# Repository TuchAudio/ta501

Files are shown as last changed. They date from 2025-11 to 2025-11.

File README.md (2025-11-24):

# ta501
Input Selector Board

## Purpose
Basic input board for **[TuchAudio 303](../../../ta303) integrated amplifier**, a.k.a. _The Bedroom Amp_, together with:

- [TuchAudio 103](../../../ta103): Phono pre-amp.
- [TuchAudio 202](../../../ta202): compact power amp.
- A generic **12V/2A power supply**

## Inputs

- **Phono:** 3.6 mV / 110 kohm. (via the [103 pre-amp](../../../ta103), otherwise same as line input)
- **Line:** 180 mV / 900 kohm.
- **Tape Playback:** thru RCA (180 mV/47 k) and DIN (0.48 V/16.5 k) connectors.

## Outputs

- Line out: 180 mV (intended for a suitable poweramp, like [TuchAudio 202](../../../ta202)).
- Tape Rec (RCA): 180 mV
- Tape Rec (DIN): 5.3 mV over 10 kohm

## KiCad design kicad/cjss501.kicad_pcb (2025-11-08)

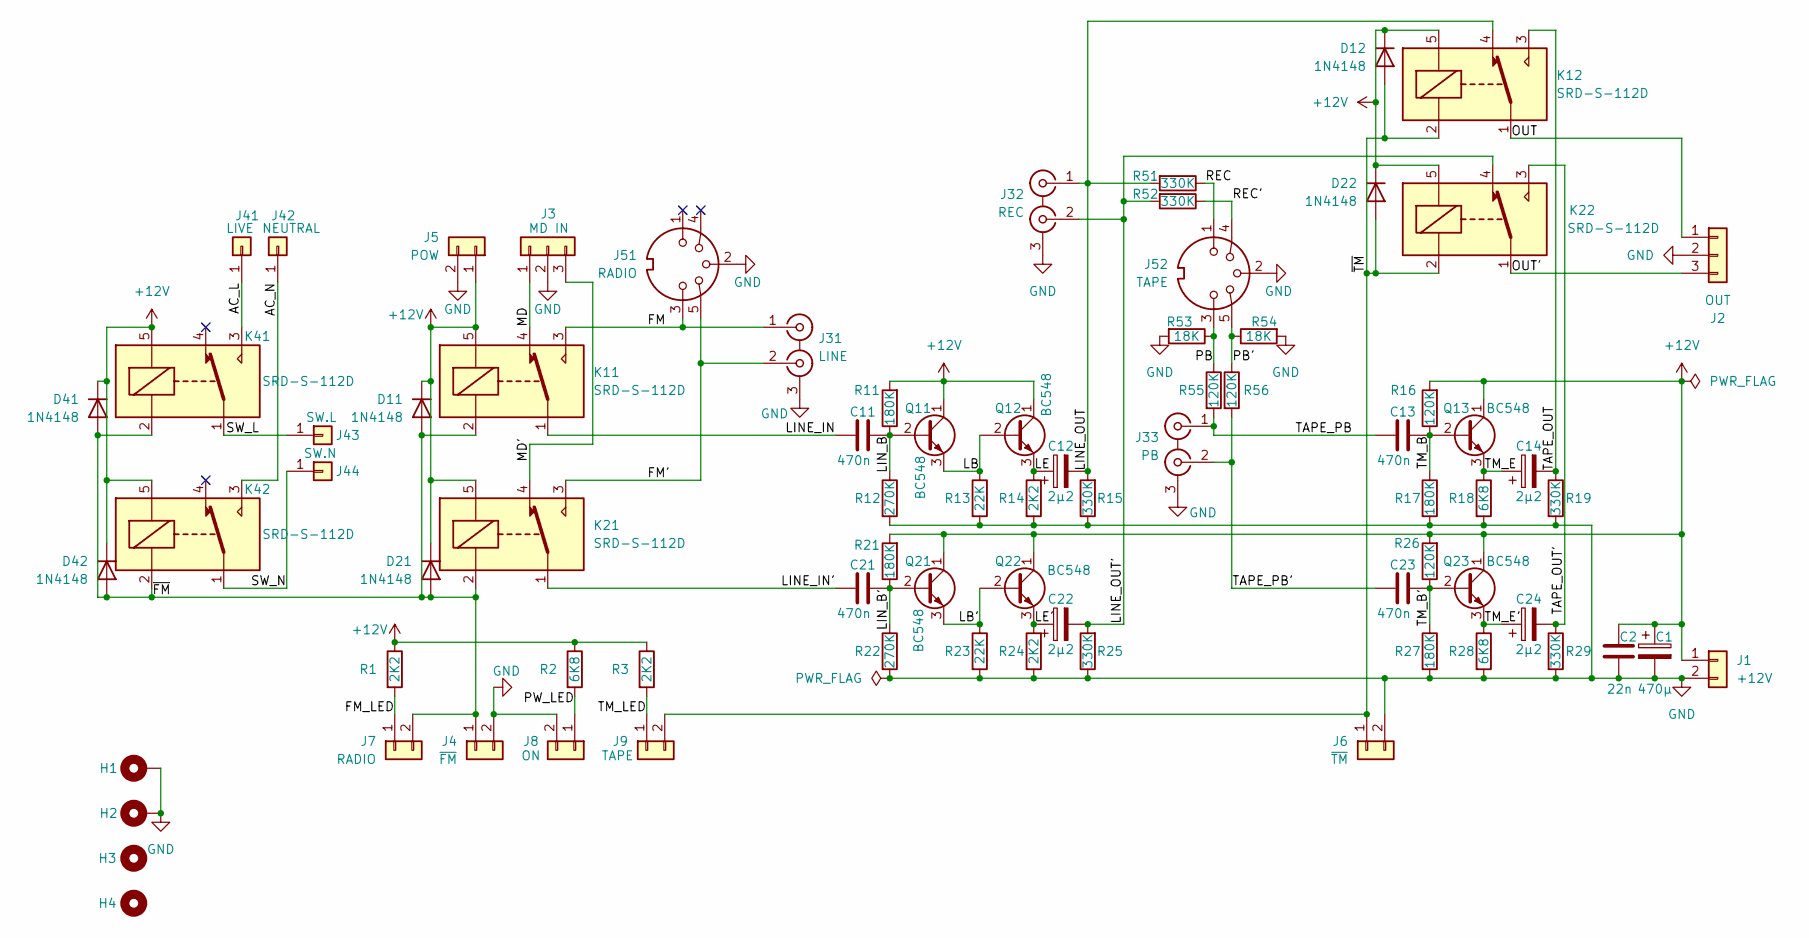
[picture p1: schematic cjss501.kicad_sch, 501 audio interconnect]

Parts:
C1: 470µ; CP_Radial_D6.3mm_P2.50mm
C2: 22n; C_Disc_D6.0mm_W2.5mm_P5.00mm
C11, C13, C21, C23: 470n; C_Rect_L7.2mm_W3.0mm_P5.00mm_FKS2_FKP2_MKS2_MKP2
C12, C14, C22, C24: 2µ2; CP_Radial_D4.0mm_P1.50mm
D11, D12, D21, D22, D41, D42: 1N4148; D_DO-35_SOD27_P7.62mm_Horizontal
H1, H2: MountingHole_Pad; MountingHole_3.2mm_M3_DIN965_Pad
H3, H4: MountingHole; MountingHole_3.2mm_M3
J1: +12V; PinHeader_1x02_P2.54mm_Vertical
J2: OUT; PinHeader_1x03_P2.54mm_Vertical
J3: MD IN; PinHeader_1x03_P2.54mm_Vertical
J4: ~{FM}; PinHeader_1x02_P2.54mm_Vertical
J5: POW; PinHeader_1x02_P2.54mm_Vertical
J6: ~{TM}; PinHeader_1x02_P2.54mm_Vertical
J7: RADIO; PinHeader_1x02_P2.54mm_Vertical
J8: ON; PinHeader_1x02_P2.54mm_Vertical
J9: TAPE; PinHeader_1x02_P2.54mm_Vertical
J31: LINE; 2xRCA_vertical
J32: REC; 2xRCA_vertical
J33: PB; 2xRCA_vertical
J41: LIVE; PinHeader_1x01_P2.54mm_Vertical
J42: NEUTRAL; PinHeader_1x01_P2.54mm_Vertical
J43: SW.L; PinHeader_1x01_P2.54mm_Vertical
J44: SW.N; PinHeader_1x01_P2.54mm_Vertical
J51: RADIO; DIN 5-180deg
J52: TAPE; DIN 5-180deg
K11, K12, K21, K22, K41, K42: SRD-S-112D; Relay_SPDT_SANYOU_SRD_Series_Form_C
Q11, Q12, Q13, Q21, Q22, Q23: BC548; TO-92_Inline
R1, R3, R14, R24: 2K2; R_Axial_DIN0207_L6.3mm_D2.5mm_P2.54mm_Vertical
R2, R18, R28: 6K8; R_Axial_DIN0207_L6.3mm_D2.5mm_P2.54mm_Vertical
R11, R17, R21, R27: 180K; R_Axial_DIN0207_L6.3mm_D2.5mm_P2.54mm_Vertical
R12, R22: 270K; R_Axial_DIN0207_L6.3mm_D2.5mm_P2.54mm_Vertical
R13, R23: 22K; R_Axial_DIN0207_L6.3mm_D2.5mm_P2.54mm_Vertical
R15, R19, R25, R29, R51, R52: 330K; R_Axial_DIN0207_L6.3mm_D2.5mm_P2.54mm_Vertical
R16, R26, R55, R56: 120K; R_Axial_DIN0207_L6.3mm_D2.5mm_P2.54mm_Vertical
R53, R54: 18K; R_Axial_DIN0207_L6.3mm_D2.5mm_P2.54mm_Vertical

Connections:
+12V: C1.1, C2.1, D11.1 (K), D12.1 (K), D21.1 (K), D22.1 (K), D41.1 (K), D42.1 (K), J1.1, J5.1, K11.5, K12.5, K21.5, K22.5, K41.5, K42.5, Q11.1 (C), Q12.1 (C), Q13.1 (C), Q21.1 (C), Q22.1 (C), Q23.1 (C), R1.1, R2.1, R3.1, R11.2, R16.2, R21.2, R26.2
/AC_L: J41.1, K41.3
/AC_N: J42.1, K42.3
/FM: J31.1 (IN1), J51.3, K11.3
/FM': J31.2 (IN2), J51.5, K21.3
/FM_LED: J7.1, R1.2
/LB: Q11.3 (E), Q12.2 (B), R13.1
/LB': Q21.3 (E), Q22.2 (B), R23.1
/LE: C12.1, Q12.3 (E), R14.1
/LE': C22.1, Q22.3 (E), R24.1
/LINE_IN: C11.1, K11.1
/LINE_IN': C21.1, K21.1
/LINE_OUT: C12.2, J32.1 (IN1), K12.4, R15.2, R51.2
/LINE_OUT': C22.2, J32.2 (IN2), K22.4, R25.2, R52.2
/LIN_B: C11.2, Q11.2 (B), R11.1, R12.1
/LIN_B': C21.2, Q21.2 (B), R21.1, R22.1
/MD: J3.1, K11.4
/MD': J3.3, K21.4
/OUT: J2.1, K12.1
/OUT': J2.3, K22.1
/PB: J52.3, R53.1, R55.1
/PB': J52.5, R54.1, R56.1
/PW_LED: J8.1, R2.2
/REC: J52.1, R51.1
/REC': J52.4, R52.1
/SW_L: J43.1, K41.1
/SW_N: J44.1, K42.1
/TAPE_OUT: C14.2, K12.3, R19.1
/TAPE_OUT': C24.2, K22.3, R29.1
/TAPE_PB: C13.1, J33.1 (IN1), R55.2
/TAPE_PB': C23.1, J33.2 (IN2), R56.2
/TM_B: C13.2, Q13.2 (B), R16.1, R17.1
/TM_B': C23.2, Q23.2 (B), R26.1, R27.1
/TM_E: C14.1, Q13.3 (E), R18.1
/TM_E': C24.1, Q23.3 (E), R28.1
/TM_LED: J9.1, R3.2
/~FM: D11.2 (A), D21.2 (A), D41.2 (A), D42.2 (A), J4.1, J7.2, K11.2, K21.2, K41.2, K42.2
/~TM: D12.2 (A), D22.2 (A), J6.1, J9.2, K12.2, K22.2
GND: C1.2, C2.2, H1.1, H2.1, J1.2, J2.2, J3.2, J4.2, J5.2, J6.2, J8.2, J31.3 (EXT), J32.3 (EXT), J33.3 (EXT), J51.2, J52.2, R12.2, R13.2, R14.2, R15.1, R17.2, R18.2, R19.2, R22.2, R23.2, R24.2, R25.1, R27.2, R28.2, R29.2, R53.2, R54.2

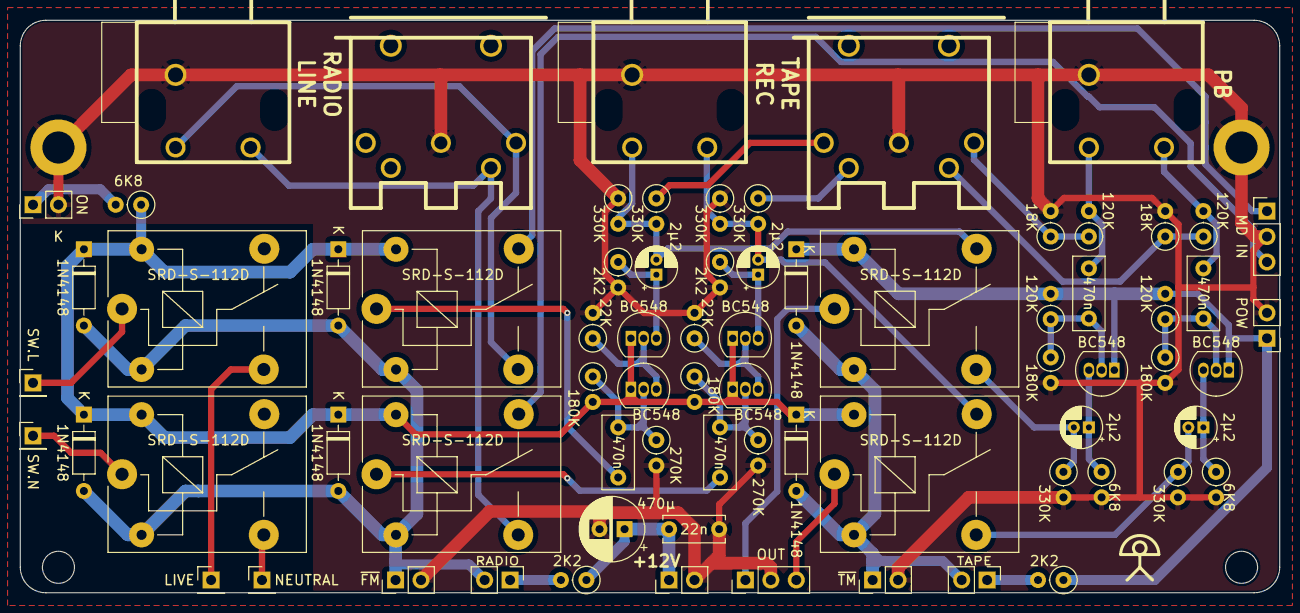
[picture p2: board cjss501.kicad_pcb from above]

Board: 2 copper layers, 125.7 x 57.1 mm, 77 parts (0 on the bottom side), 39 nets.
